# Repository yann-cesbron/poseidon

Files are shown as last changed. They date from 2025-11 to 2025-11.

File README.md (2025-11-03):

# Poseidon
Drone marin - projet pedagogique

Dans le cadre de la Fête de la Science 2024, 
   notre association Electromakers a présenté ce drone marin
L’idée est de sensibiliser le public aux enjeux liés à la pollution et à l’étude des océans.

Ce projet permet de présenter en direct des mesures environnementales et des démonstrations lors des animations.

OBJECTIF
- Mesurer température, pH et turbidité de l’eau.
- Réaliser des prélèvements avec éprouvettes IFREMER.
- Transmettre les données en temps réel.
- Disposer d’une caméra embarquée.
 
Spécifications Techniques
Dimensions : 1,25 m / 10 kg max.
Semi-immergé

Les capteurs :
	Température DS18B20 
  pH résistante eau salée.
	Turbidité en continu.
	Pompe péristaltique

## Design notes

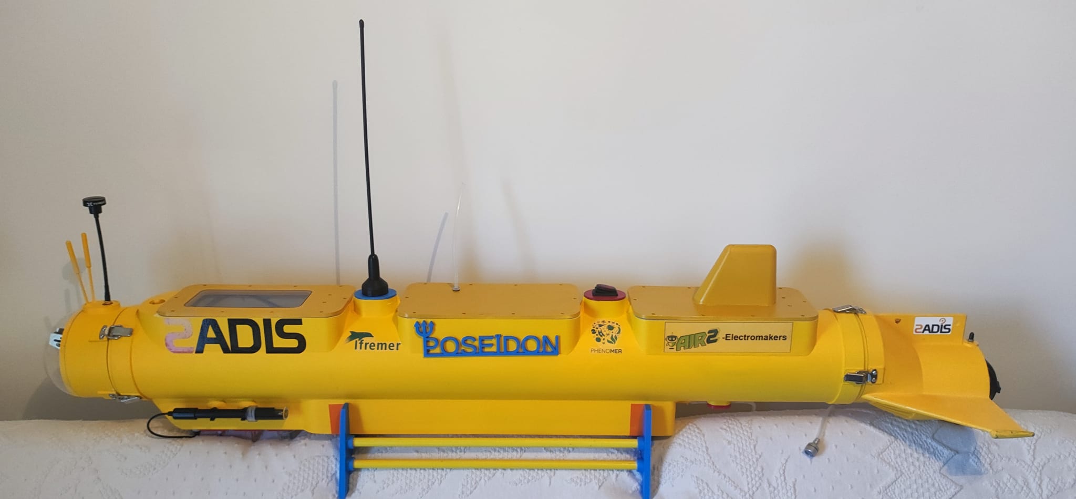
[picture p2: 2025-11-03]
Poseidon.jpg

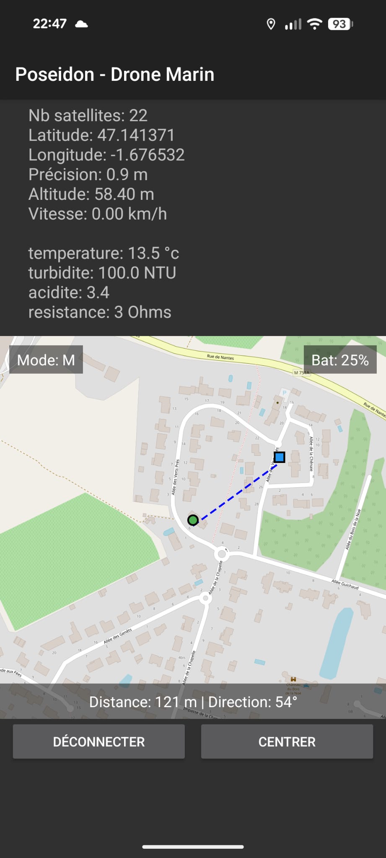
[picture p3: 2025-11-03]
Android/applicationAndroid.jpg

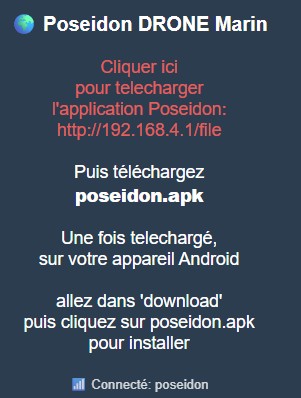
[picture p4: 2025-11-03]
Android/modeOpTelechargementAPK.jpg

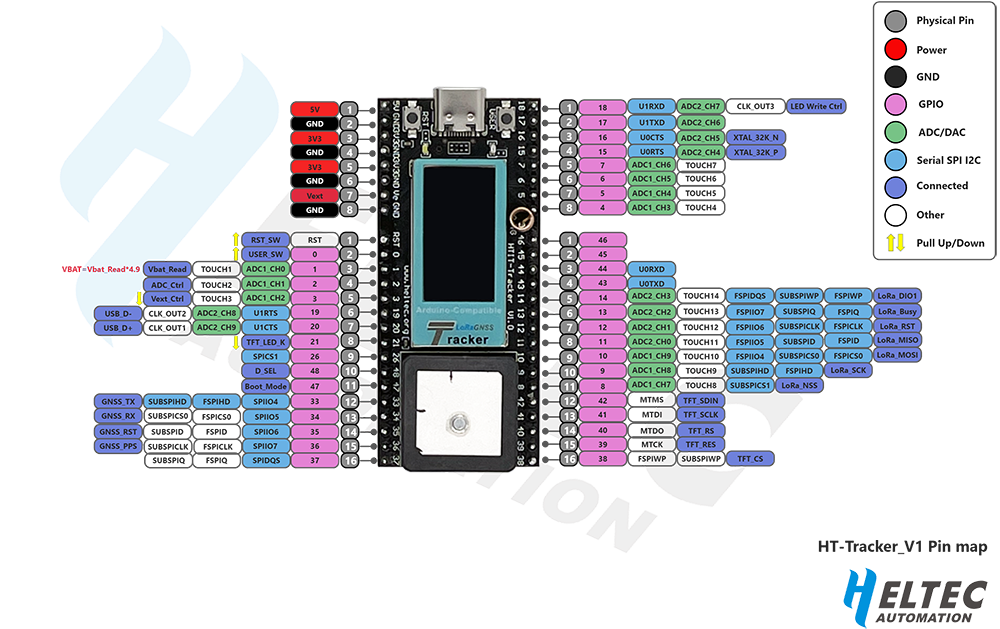
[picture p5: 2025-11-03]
ESPsensors/espS3Heltec.png

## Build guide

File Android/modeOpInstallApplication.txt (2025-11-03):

TELECHARGEMENT Mettre la passerelle en mode 'Serveur':
  1- maintenir le bouton enfoncé et mettre en marche.
		un point d'acces 'poseidon' est alors visible en wifi
  2- s'y connecter, mdp: 'Poseidon'
  3- avec un navigateur, se connecter à 192.168.4.1
        la page d'accueil s'affiche
  4- cliquer sue le texte en rouge pour telecharger
  5- répondre aux questions du smartphone

UTILISATION Mettre la passerelle en mode bluetooth
  * le smartphone doit etre connécté à internet
      sinon.. pas de carte
  1- associer le nouveau peripherique bluetooth 'poseidon'
  2- demarrer l'application
  3- presser le bouton connexion
  4- attendre l'arrivée des données ...

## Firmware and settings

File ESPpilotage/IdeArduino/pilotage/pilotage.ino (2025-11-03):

#include <ArduinoJson.h>
#include <pins.h>

// --- Définitions des Broches (Pins) (Inchangé) ---
// const int PIN_COMMUTATEUR = 15;
// const int PIN_LED_RX = 2;
// const int PIN_RX2 = 16;
// const int PIN_TX2 = 17;

// --- Constantes de Communication et Minuteries (Inchangé) ---
const long INTERVALLE_POTENTIOMETRE = 30000;  // 30s
const long INTERVALLE_PILOTE = 1000;          // 1s
const long DELAI_LED_RX = 100;
const long BAUD_RATE_COMM = 19200;

// --- Variables d'État  ---
unsigned long derniereLecturePot = 0;
unsigned long dernierAjustGouvernail = 0;
int etatCommutateurPrecedent = HIGH;
String modeOperation = "M";

// --- Variables Globales pour le Stockage des Coordonnées ---
double gps_lat = 0.0;
double gps_lng = 0.0;
double wp_lat = 0.0;
double wp_lng = 0.0;
double distance_m = 0.0;
double cap_deg = 0.0;

// batterie
int niveauBatterie = 0;
// Tension de Référence de l'ADC de l'ESP32 (Vref)
const float VREF = 3.3;
// Résolution de l'ADC (12 bits)
const int ADC_MAX_VALUE = 4095;
// Facteur de conversion V / ADC_Value (VREF / 4095)
const float V_PER_UNIT = VREF / ADC_MAX_VALUE;

// --- BORNES DE CALIBRATION DU POURCENTAGE (en Volts mesurés sur l'ADC) ---
// Tension ADC pour 18.0V batterie (0%) -> 2.75V
const float V_ADC_MIN = 2.75;
// Tension ADC pour 19.0V batterie (100%) -> 2.90V
const float V_ADC_MAX = 2.90;
// Plage de tension ADC utilisable
const float V_ADC_RANGE = V_ADC_MAX - V_ADC_MIN;


// --- Déclaration des Fonctions  ---
void envoyerJson(int bat, String mode);
void lireEtTraiterSerial2();

// --- SETUP et LOOP ---
void setup() {
  Serial.begin(115200);
  Serial.println("Démarrage du système ESP32 (v5.0 - WP/GPS Affichage Corrigé)...");
  Serial2.begin(BAUD_RATE_COMM, SERIAL_8N1, PIN_RX2, PIN_TX2);
  Serial.print("Communication série (RX/TX) démarrée sur GPIO 16/17 à ");
  Serial.print(BAUD_RATE_COMM);
  Serial.println(" bauds.");

  pinMode(PIN_MODE, INPUT_PULLUP);
  pinMode(PIN_LED_RX, OUTPUT);
  digitalWrite(PIN_LED_RX, LOW);

  analogSetAttenuation(ADC_11db); // pour 0-3.3V
  // 1ere lecture batterie
  int adcValue = analogRead(PIN_BATTERIE);
  niveauBatterie = calculateBatteryPercent(adcValue);

  etatCommutateurPrecedent = digitalRead(PIN_MODE);
  modeOperation = (etatCommutateurPrecedent == LOW) ? "A" : "M";
  //  init bousole
  initBousole();
  //   init du servomoteur
  initialiserServos();
}

void loop() {
  unsigned long tempsActuel = millis();

  // 1. Gestion du Commutateur (Changement d'état)
  int etatCommutateurActuel = digitalRead(PIN_MODE);
  if (etatCommutateurActuel != etatCommutateurPrecedent) {
    delay(50);
    etatCommutateurActuel = digitalRead(PIN_MODE);

    if (etatCommutateurActuel != etatCommutateurPrecedent) {
      modeOperation = (etatCommutateurActuel == HIGH) ? "A" : "M";
      Serial.print("MODE: Changement d'état. Nouveau mode: ");
      Serial.println(modeOperation);
      envoyerJson(niveauBatterie, modeOperation);
      etatCommutateurPrecedent = etatCommutateurActuel;
    }
  }

  // 2. Lecture niveau batterie (Toutes les 60 secondes)
  if (tempsActuel - derniereLecturePot >= INTERVALLE_POTENTIOMETRE) {
    derniereLecturePot = tempsActuel;
    int adcValue = analogRead(PIN_BATTERIE);
    niveauBatterie = calculateBatteryPercent(adcValue);
    float vBatt = ((float)adcValue * V_PER_UNIT) * 6.5517;  // Conversion pour affichage
    Serial.print("V_Batterie: ");
    Serial.print(vBatt, 2);
    Serial.print(" V -> Charge: ");
    Serial.print(niveauBatterie);
    Serial.println(" %");

    envoyerJson(niveauBatterie, modeOperation);
  }

  // 3. Traitement des données reçues sur Serial2 (RX)
  lireEtTraiterSerial2();

  if (millis() - dernierAjustGouvernail >= INTERVALLE_PILOTE) {
    dernierAjustGouvernail = millis();
    if (gps_lat != 0.0 && wp_lat != 0.0 && cap_deg != 0.0 && modeOperation == "A") {
      Serial.println("------- ajustement gouvernail");
      ajusterGouvernail(cap_deg);
    }
  }
}

// -----------------------------------------------------------------------------
// --- Fonctions d'Envoi (TX) (Inchangé) ---
// -----------------------------------------------------------------------------

/**
 * Génère et envoie le message JSON sur Serial2. Format: {"bat":XX,"mode":"Y"}
 */
void envoyerJson(int bat, String mode) {
  StaticJsonDocument<64> doc;
  doc["bat"] = bat;
  doc["mode"] = mode;

  if (serializeJson(doc, Serial2) == 0) {
    Serial.println("Erreur de sérialisation JSON TX.");
  } else {
    Serial2.println();
    
    Serial.print("TX JSON: ");
    serializeJson(doc, Serial);
    Serial.println();
  }
}

// -----------------------------------------------------------------------------
// --- Fonctions de Réception et Traitement (RX)  ---
// -----------------------------------------------------------------------------

/**
 * Lit, affiche, traite les messages JSON reçus et déclenche les calculs.
 */
void lireEtTraiterSerial2() {
  static String inputString = "";
  static unsigned long tempsExtinctionLed = 0;

  if (digitalRead(PIN_LED_RX) == HIGH && millis() > tempsExtinctionLed) {
    digitalWrite(PIN_LED_RX, LOW);
  }

  while (Serial2.available()) {
    // ... (Code de lecture de la trame et gestion LED inchangé) ...
    char inChar = (char)Serial2.read();
    inputString += inChar;
    digitalWrite(PIN_LED_RX, HIGH);
    tempsExtinctionLed = millis() + DELAI_LED_RX;

    if (inChar == '\n' || inChar == '\r') {
      inputString.trim();

      if (inputString.length() > 0) {
        // Serial.print("RX Trame brute: ");
        // Serial.println(inputString);

        String prefixe;
        String jsonPayload;
        int debutJson = inputString.indexOf(':');

        if (debutJson != -1) {
          prefixe = inputString.substring(0, debutJson);
          jsonPayload = inputString.substring(debutJson + 1);
          prefixe.toUpperCase();

          if (prefixe.equals("GPS") || prefixe.equals("WP")) {
            StaticJsonDocument<256> doc;
            DeserializationError error = deserializeJson(doc, jsonPayload);

            if (!error) {
              if (doc.containsKey("lat") && doc.containsKey("lng")) {
                double lat = doc["lat"];
                double lng = doc["lng"];

                Serial.println("--- DONNÉES REÇUES ---");

                if (prefixe.equals("GPS")) {
                  gps_lat = lat;  // Stockage de la dernière coordonnée GPS
                  gps_lng = lng;
                  Serial.print("GPS lat: ");
                  Serial.println(gps_lat, 6);
                  Serial.print("GPS lng: ");
                  Serial.println(gps_lng, 6);
                } else if (prefixe.equals("WP")) {
                  wp_lat = lat;  // Stockage de la dernière coordonnée WP
                  wp_lng = lng;
                  Serial.print("WP lat: ");
                  Serial.println(wp_lat, 6);
                  Serial.print("WP lon: ");
                  Serial.println(wp_lng, 6);  // Affichage en 'lon'
                }
                Serial.println("---------------------");
                if (modeOperation == "A") {
                  // --- NOUVEAU: Appel des Calculs ---  si mode 'auto'
                  // Les calculs sont déclenchés dès qu'une nouvelle coordonnée valide arrive
                  if (gps_lat != 0.0 && wp_lat != 0.0) {  // Vérifie si les deux points sont initialisés
                    distance_m = calculerDistance(gps_lat, gps_lng, wp_lat, wp_lng);
                    cap_deg = calculerCap(gps_lat, gps_lng, wp_lat, wp_lng);

                    Serial.println("=== CALCUL DE NAVIGATION ===");
                    Serial.print("Distance GPS -> WP: ");
                    if (distance_m > 10.0) {
                      set_motor(true);  // on
                    } else {
                      set_motor(false);  // off
                    }

                    if (distance_m < 1000.0) {
                      Serial.print(distance_m, 2);
                      Serial.println(" mètres");
                    } else {
                      Serial.print(distance_m / 1000.0, 3);
                      Serial.println(" km");
                    }

                    Serial.print("Direction (Cap): ");
                    Serial.print(cap_deg, 1);
                    Serial.println(" degrés (Nord=0)");
                    Serial.println("============================");
                    // ajustement gouvernail
                    ajusterGouvernail(cap_deg);
                  } else {
                    Serial.println("Attente de la deuxième coordonnée (GPS ou WP) pour le calcul.");
                  }
                } else {
                  Serial.println("mode manuel.. on ne fait rien");
                }

              } else {
                Serial.print("Trame ");
                Serial.print(prefixe);
                Serial.println(" reçue, mais 'lat' et/ou 'lng' manquent.");
              }
            } else {
              Serial.print("Erreur de désérialisation JSON (");
              Serial.print(prefixe);
              Serial.print("): ");
              Serial.println(error.c_str());
            }

          } else if (prefixe.equals("SEN")) {
            // Serial.println("Trame SEN: ignorée.");
          } else {
            // Serial.print("Préfixe non reconnu: ");
            // Serial.println(prefixe);
          }
        } else {
          // Serial.println("Trame reçue sans préfixe ou séparateur ':'.");
        }
      }
      inputString = "";  // Réinitialiser la chaîne pour le prochain message
    }
  }
}

/**
 * @brief Convertit la valeur brute de l'ADC en pourcentage de batterie utilisable (0 à 99%).
 * * @param rawADC La lecture brute du pin analogique (0 à 4095).
 * @return int Le pourcentage de batterie (0-99).
 */
int calculateBatteryPercent(int rawADC) {

  // 1. Convertir la lecture brute en tension réelle sur le pin ADC
  float vAdc = (float)rawADC * V_PER_UNIT;
  // 2. Calculer la position actuelle dans la plage utilisable
  // La tension doit être décalée par V_ADC_MIN
  float vOffset = vAdc - V_ADC_MIN;
  // 3. Calculer le pourcentage théorique (0.0 à 1.0)
  float percentFloat = vOffset / V_ADC_RANGE;
  // 4. Convertir en pourcentage (0 à 100)
  int percent = round(percentFloat * 100.0);
  // 5. Limiter le résultat dans la plage [0, 99]
  if (percent < 0) {
    return 0;
  }
  if (percent > 99) {
    return 99;  // Limité à 99% comme demandé
  }
  return percent;
}

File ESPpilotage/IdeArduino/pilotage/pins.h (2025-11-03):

#ifndef PINS_H
#define PINS_H

// Composant,Broche ESP32 DevKit V1
// Bouton,GPIO 15,Entrée,Câbler le bouton entre GPIO 15 et GND. Le code utilise INPUT_PULLUP.
// RX de la Communication,GPIO 16 (RX2),Entrée Série,Câbler au TX de l'appareil externe.
// TX de la Communication,GPIO 17 (TX2),Sortie Série,Câbler au RX de l'appareil externe.
// i2c  SCL 22 , SDA 21
// led
#define PIN_LED_RX 2

// servo gouvernail
#define PIN_SERVO_GOUVERNAIL 13
#define PIN_SERVO_MOTEUR 12

// buton
#define PIN_MODE 15  // pour le mode A ou M

#define PIN_BATTERIE 4

//  RX/TX  sur serial2
#define PIN_RX2 16  // à connecter à pin 45 du heltec
#define PIN_TX2 17  // à connecter à pin 46
#endif

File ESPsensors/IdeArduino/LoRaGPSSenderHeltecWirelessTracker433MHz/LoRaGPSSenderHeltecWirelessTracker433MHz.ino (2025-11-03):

//-- 26/10/2024 YC
// version 0.9
#include "Arduino.h"
#include <OneWire.h>
#include <DallasTemperature.h>

// Please provide a correct license! For more information:
// http://www.heltec.cn/search/
//-- License key
// ESP32ChipID=3C1A3B43CA48  Heltec 1.2
// uint32_t license[4] = { 0x1509E5FF, 0x936FFF81, 0xD99CDDAC, 0x6648BDD0 };

// ESP32ChipID=90793B43CA48  Heltec 1.1
uint32_t license[4] = { 0x3A4EAB51, 0xC9738BA8, 0xD40D6062, 0x29233553 };

//-- LORA
#include "LoRaWan_APP.h"
//-- GPS
#include "HT_TinyGPS++.h"
TinyGPSPlus GPS;

//-- Pour le format JSON
#include <ArduinoJson.h>

// UART2 connecté à l'ESP2
#define SERIAL2_TX_PIN 45
#define SERIAL2_RX_PIN 46
HardwareSerial Esp2_serial(2);  // vers esp32 arriere
String receivedFromEsp2 = "";   // buffer pour send vers ESP2

//====================================  Afficheur
#include <Adafruit_GFX.h>     // Core graphics library
#include <Adafruit_ST7735.h>  // Hardware-specific library for ST7735
#include <Adafruit_ST7789.h>  // Hardware-specific library for ST7789
#include <Fonts/FreeMono9pt7b.h>
#include <Fonts/FreeSans12pt7b.h>
// Broches pour Wireless Tracker ESP32-S3 Version 1.1
#define TFT_CS 38
#define TFT_DC 40
#define TFT_RST 39
#define TFT_BACKLIGHT 3  // Display backlight pin
#define TFT_LED_K_Pin 21

#define TFT_MOSI 42  // Data out
#define TFT_SCLK 41  // Clock out
Adafruit_ST7789 tft = Adafruit_ST7789(TFT_CS, TFT_DC, TFT_MOSI, TFT_SCLK, TFT_RST);

// couleur exprimée en format 16 bits BGR (souvent appelé RGB565)
const uint16_t Display_Color_Black = 0x0000;
const uint16_t Display_Color_Blue = 0xF800;
const uint16_t Display_Color_Red = 0x001F;
const uint16_t Display_Color_Green = 0x07E0;
const uint16_t Display_Color_Cyan = 0x07FF;
const uint16_t Display_Color_Magenta = 0xF81F;
const uint16_t Display_Color_Yellow = 0xFFE0;
const uint16_t Display_Color_Orange = 0x02BF;
const uint16_t Display_Color_White = 0xFFFF;

// The colors we actually want to use
uint16_t Display_Text_Color = Display_Color_Black;
uint16_t Display_Backround_Color = Display_Color_Blue;

//====================================  Capteurs ========================================================
//-- Entreés analogiques
// const uint16_t TEST = 4;  utilisée par oneWire
const uint16_t PH_Po = 5;
const uint16_t RES_AO = 6;
const uint16_t TURB_Ao = 7;
float kADC = 0.87;
float attenuationADC = pow(10, 11.0 / 20.0) * kADC;

#define LED 18
#define MIN_NB_SAT 3

//======================== Capteur Température:  DS18B20 ======================

// Data wire is plugged into port 0 on the Arduino
#define ONE_WIRE_BUS 4
#define TEMPERATURE_PRECISION 9  // Lower resolution
// Setup a oneWire instance to communicate with any OneWire devices (not just Maxim/Dallas temperature ICs)
OneWire oneWire(ONE_WIRE_BUS);
// Pass our oneWire reference to Dallas Temperature.
DallasTemperature Tsensor(&oneWire);

//========================================== GPS ========================================================
#define TX 34
#define RX 33
#define GPS_OK 36
#define VGNSS_CTRL 3

//========================================== one wire ========================================================
#define ONE_WIRE_BUS 4

//========================================== LORA ========================================================
// Paramètres radio - DOIVENT ÊTRE IDENTIQUES aux deux devices
#define RF_FREQUENCY 433775000   // Hz
#define TX_OUTPUT_POWER 14       // dBm
#define LORA_BANDWIDTH 0         // 0: 125 kHz
#define LORA_SPREADING_FACTOR 7  // SF7
#define LORA_CODINGRATE 1        // 4/5
#define LORA_PREAMBLE_LENGTH 8
#define LORA_SYMBOL_TIMEOUT 0
#define LORA_FIX_LENGTH_PAYLOAD_ON false
#define LORA_IQ_INVERSION_ON false

#define BUFFER_SIZE 200  // Augmenté pour accommoder le JSON

// Buffer pour l'emission' LoRa
char txpacket[BUFFER_SIZE];
char rxpacket[BUFFER_SIZE];

static RadioEvents_t RadioEvents;
void OnTxDone(void);
void OnTxTimeout(void);
void OnRxDone(uint8_t *payload, uint16_t size, int16_t rssi, int8_t snr);

// Variables pour le mode asynchrone
int16_t packetCounter = 0;
int16_t lastRssi = 0;
int8_t lastSnr = 0;
bool isTransmitting = false;
unsigned long lastTxTime = 0;
#define TX_INTERVAL 5000  // Envoi alternativement les trames toutes les 5 secondes
bool flagTr = false;      // sert à envoyer altenativement les 2 trames

int batteryValue = 0;  // pour stocker la valeur "bat" recue de l'ESP2
char driveMode = 'M';  // pour stocker le mode 'M', 'A'

// Données capteurs partagées
float temperature = 0.0;
float turbidite = 0.0;
float resistivite = 0.0;
float ph = 0.0;

SemaphoreHandle_t dataMutex;

// --- Fonction d’arrondi à 1 décimale ---
float arrondir1(float value) {
  return roundf(value * 10.0f) / 10.0f;
}

// --- Tâche lecture capteurs ---
void taskLectureCapteurs(void *pvParameters) {
  float _temperature = 0.0;
  float _turbidite = 0.0;
  float _resistivite = 0.0;
  float _ph = 0.0;

  for (;;) {
    // Serial.println("-- début lecture capteurs");
    _temperature = arrondir1(lectureTemp());
    _turbidite = arrondir1(lectureTurbidite());
    _resistivite = arrondir1(LectureResistivite());
    _ph = arrondir1(LecturePH());
    xSemaphoreTake(dataMutex, portMAX_DELAY);  // protege les variables partagées
    temperature = _temperature;
    turbidite = _turbidite;
    resistivite = _resistivite;
    ph = _ph;
    xSemaphoreGive(dataMutex);
    // Serial.println("-- fin mise à jour capteurs");
    vTaskDelay(pdMS_TO_TICKS(5000));  // toutes les 5s
  }
}

void sendGPSData(void) {
  StaticJsonDocument<256> doc;
  // Données GPS uniquement
  // if (GPS.location.isValid()) {
  doc["lat"] = GPS.location.lat();
  doc["lng"] = GPS.location.lng();
  doc["alt"] = GPS.altitude.meters();
  doc["sat"] = GPS.satellites.value();
  doc["hdop"] = GPS.hdop.value() / 100.0;
  // }
  // Heure
  // if (GPS.time.isValid()) {
  doc["hour"] = GPS.time.hour();
  doc["minute"] = GPS.time.minute();
  doc["second"] = GPS.time.second();
  // }
  // Date
  // if (GPS.date.isValid()) {
  doc["year"] = GPS.date.year();
  doc["month"] = GPS.date.month();
  doc["day"] = GPS.date.day();
  // }

  // Metadata
  // doc["id"] = "HTIT-Tracker";
  // doc["type"] = "gps";
  doc["ts"] = millis();

  String jsonString;
  serializeJson(doc, jsonString);

  String message = "GPS:" + jsonString;

  if (message.length() >= BUFFER_SIZE) {
    Serial.println("ERREUR: Trame GPS trop longue!");
    return;
  }

  message.toCharArray(txpacket, BUFFER_SIZE);
  digitalWrite(LED, HIGH);

  isTransmitting = true;
  Radio.Send((uint8_t *)txpacket, strlen(txpacket));

  flagTr = true;
  lastTxTime = millis();

  Serial.print("=== Envoi trame GPS ===");
  Serial.print("Taille: ");
  Serial.print(strlen(txpacket));
  Serial.println(" octets");
  Serial.println(jsonString);
  forwardToEsp2Serial(txpacket);  //  Envoi vers ESP2
}
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

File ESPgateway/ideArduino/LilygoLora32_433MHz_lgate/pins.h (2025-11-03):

#ifndef PINS_H
#define PINS_H


// led
#define EMBEDDED_LED 25

// buton at start, enable wifi for web server & disable BT
#define WIFI_MODE_BUTTON 0

// Batterie analog
#define BATTERY_PIN 35

// =======================================  Carte SD (HSPI) ==============================
#define SD_CS    13
#define SD_MISO  2
#define SD_MOSI  15
#define SD_SCK   14

// =======================================  LoRa (VSPI) ==================================
#define LORA_SS   18
#define LORA_RST  23
#define LORA_DIO0 26
#define LORA_SCK  5
#define LORA_MISO 19
#define LORA_MOSI 27

// =======================================  Display OLED =================================
#define OLED_SDA 21
#define OLED_SCL 22
#define OLED_RST -1
#endif
